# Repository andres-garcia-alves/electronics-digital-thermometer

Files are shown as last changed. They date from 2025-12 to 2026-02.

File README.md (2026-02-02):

# Digital Thermometer

Arduino code for a digital thermometer (temperature, humidity and heat index) with auto-OFF functionality.

&nbsp;

This project use the following electronic components:
- 1 x Arduino UNO / Nano v3
- 1 x DHT11 temperature/humidity sensor
- 1 x Display 5461AS, 7 segment, 4 digit, common anode
- 8 x 1k ohm resistors
- 1 x 10k ohm resistor
- 1 x Transistor BC547 NPN
- 1 x Electrolitic capacitor 470uF 10v
- 1 x Push-button
- 1 x Batery 9v

The circuit:
- Pressing the push-button charges the capacitor and puts the transistor in conducting state.
- After the button is released, the capacitor continues to power the base of the transistor for around 20 seconds.
- The current through the transistor powers the Arduino (and rest of the thermometer).
- Arduino constrols the temperature+humidity measurement and the multiplexing process for the 4 digit display.

Notes:
- This thermometer automatically turns off approximately 20 seconds after activation.
- To increase this time, change the capacitor to one of higher capacitance.
- Edit `Definitions.h` to adjust configured display pins to your own display model.

&nbsp;

### Screenshots

| Schematics Diagram | PCB Layout |
|---|---|
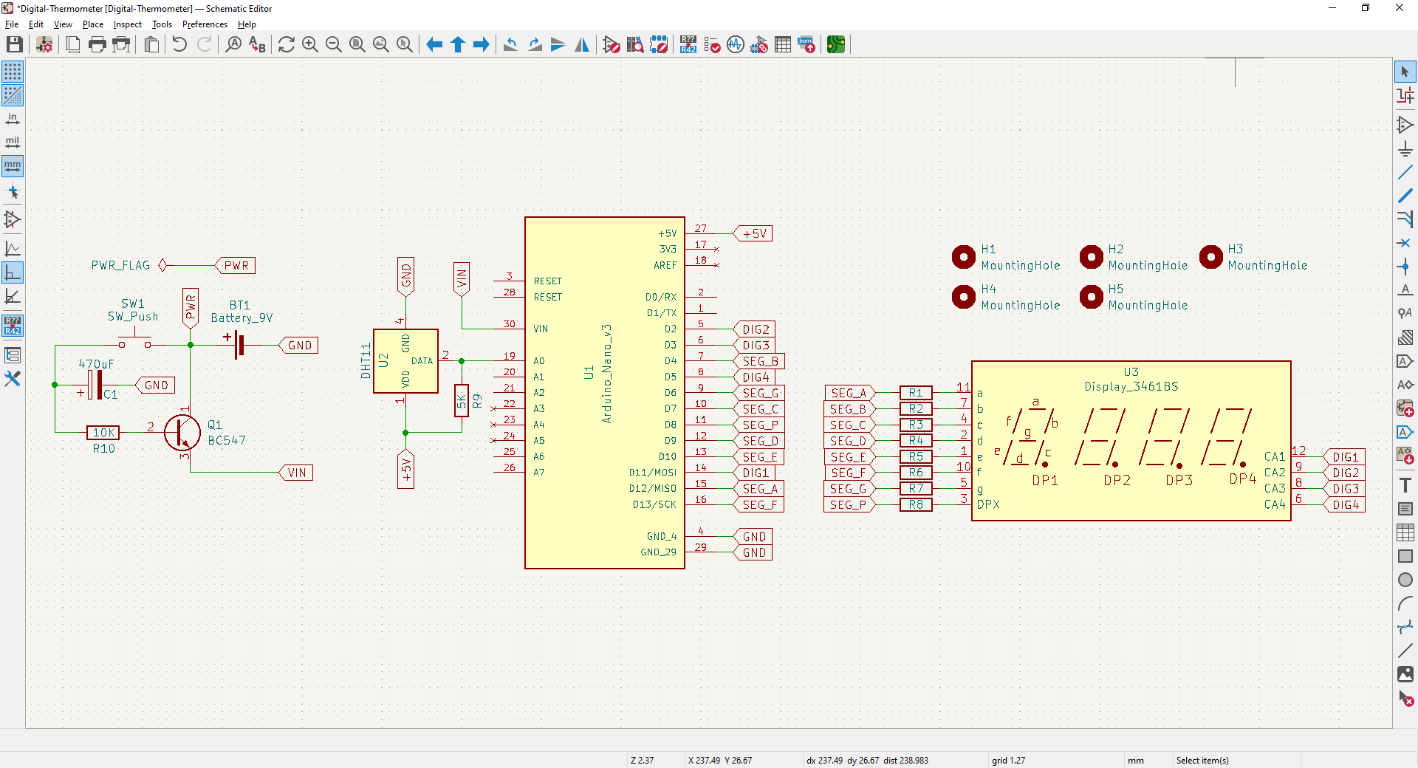
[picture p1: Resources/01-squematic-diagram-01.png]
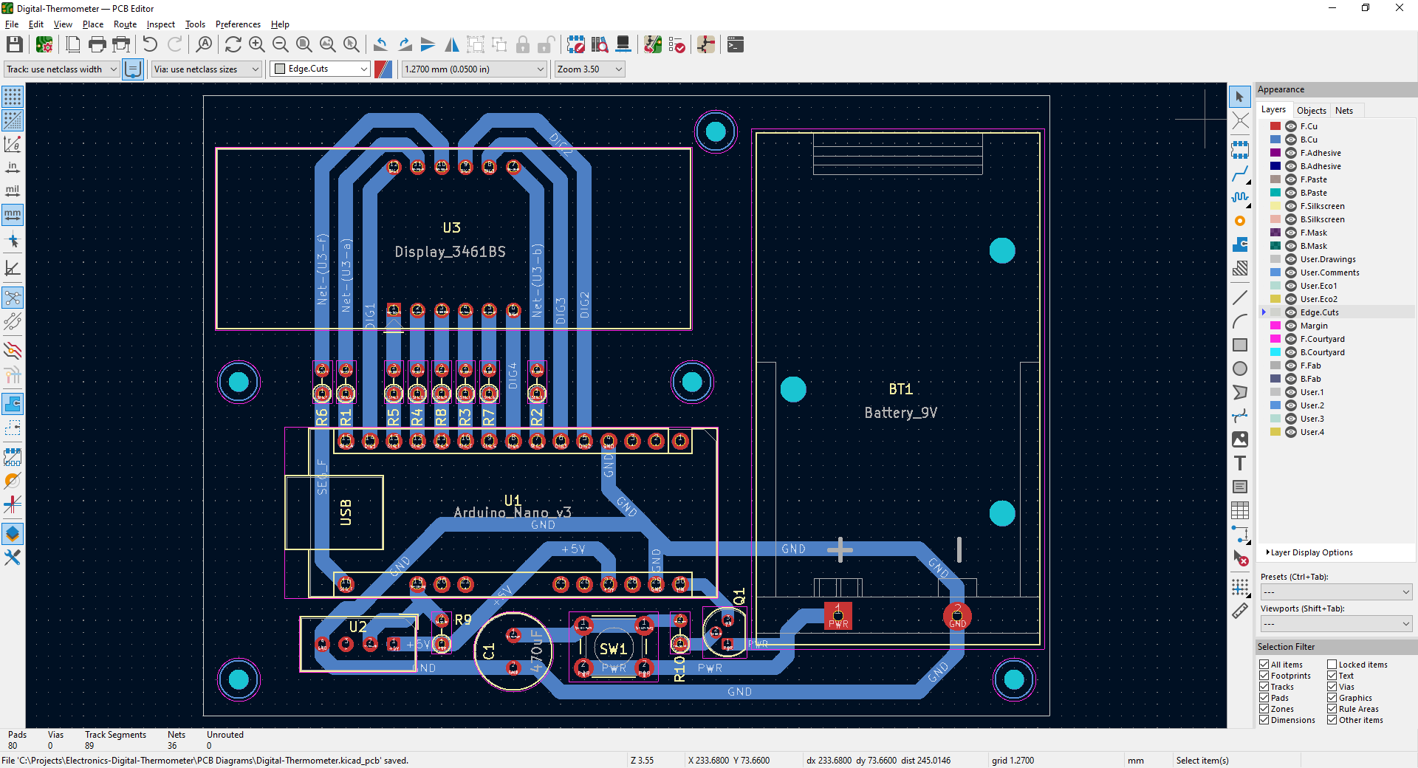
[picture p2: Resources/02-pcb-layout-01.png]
|  |  |

| PCB 3D Render | PCB 3D Render |
|---|---|
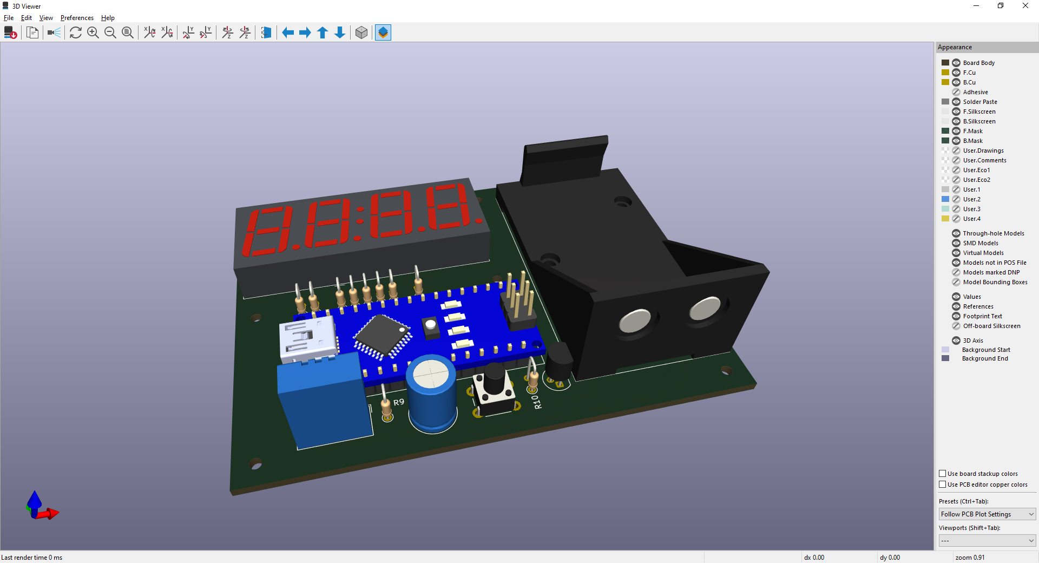
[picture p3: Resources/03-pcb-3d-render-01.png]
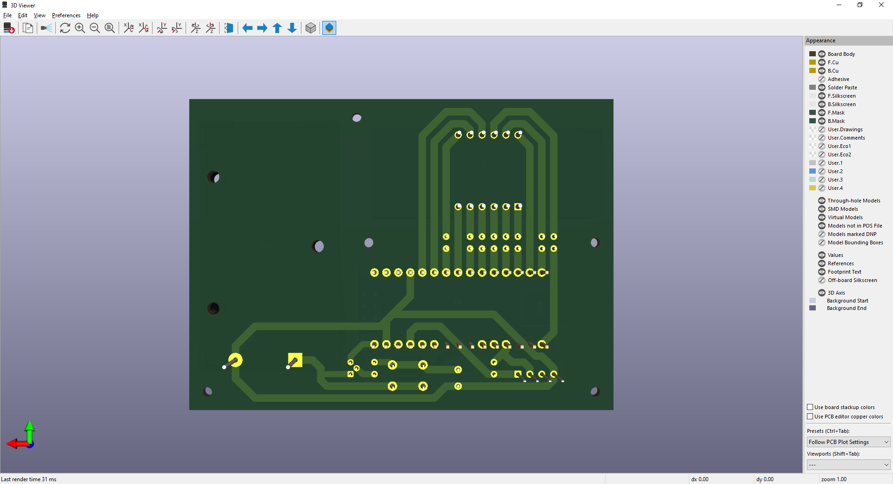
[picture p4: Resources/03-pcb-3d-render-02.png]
|  |  |

| Prototype | Building |
|---|---|
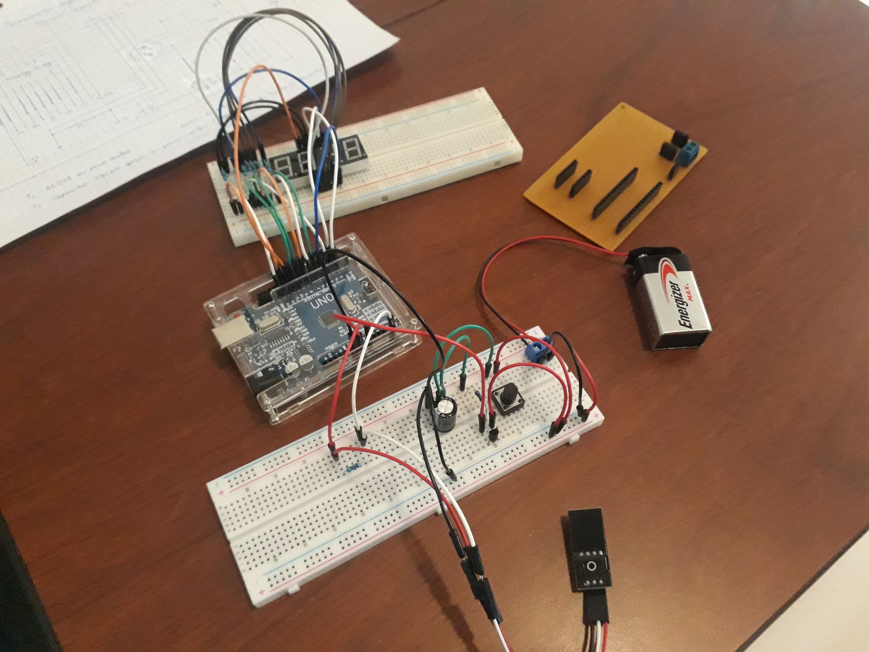
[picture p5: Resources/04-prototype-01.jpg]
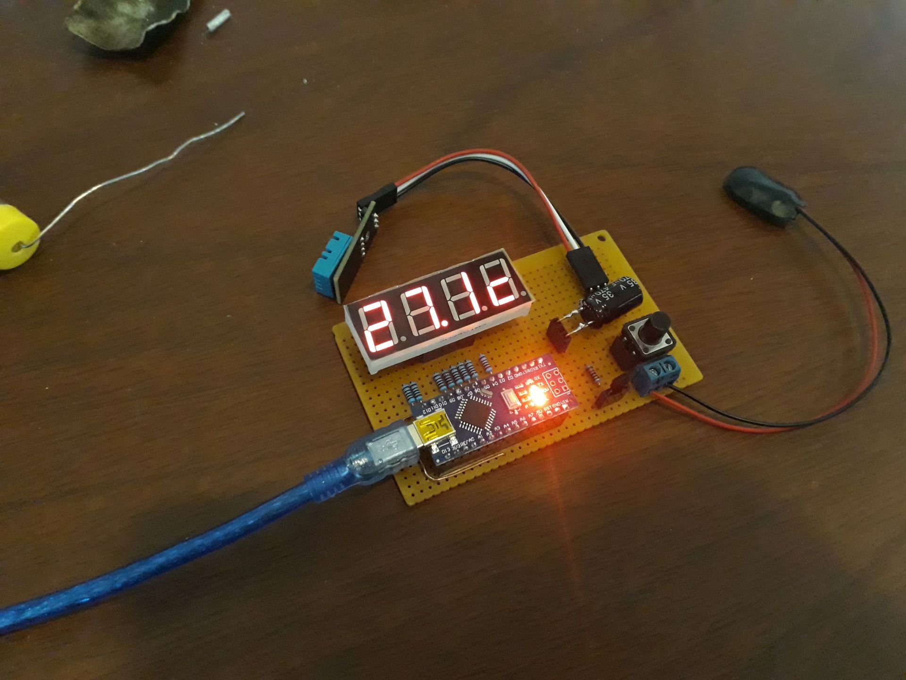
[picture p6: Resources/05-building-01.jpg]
|  |  |

| Building | Building |
|---|---|
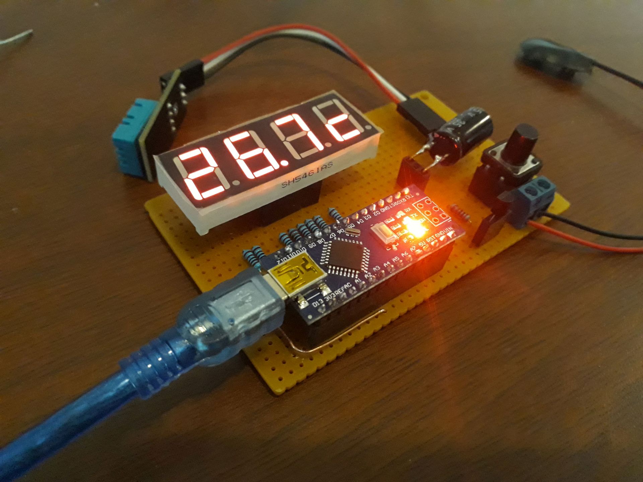
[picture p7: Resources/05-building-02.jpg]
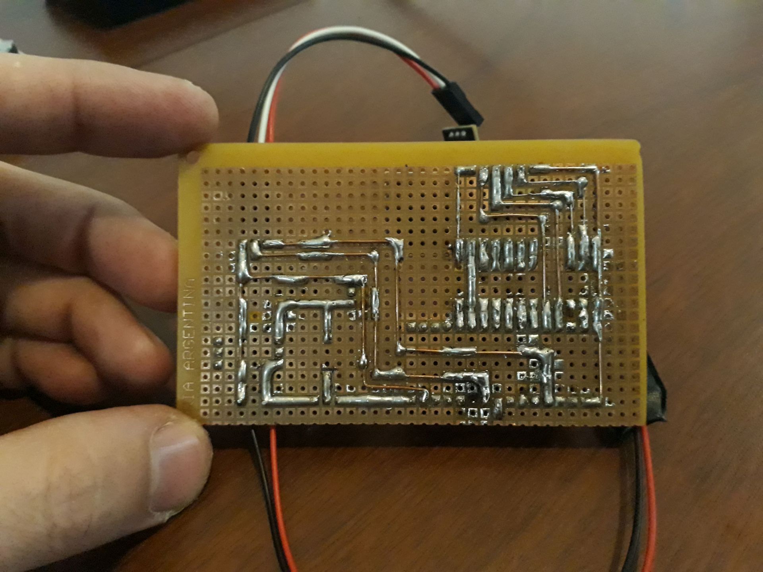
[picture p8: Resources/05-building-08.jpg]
|  |  |

| Box Shaping | Box Shaping |
|---|---|
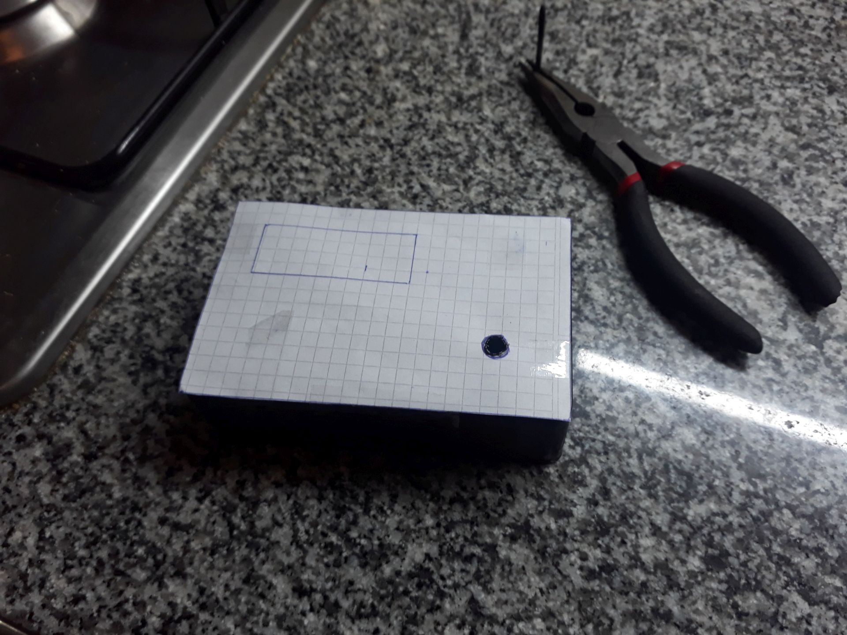
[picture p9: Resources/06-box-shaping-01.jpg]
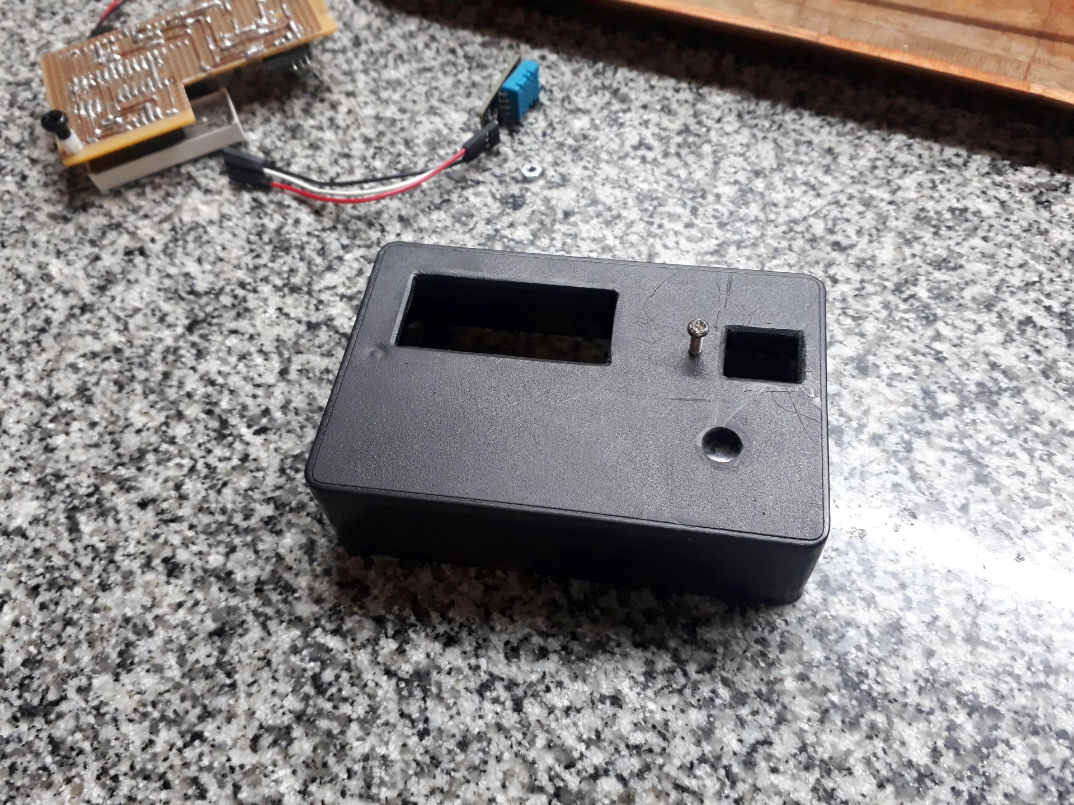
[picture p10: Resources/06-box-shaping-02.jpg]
|  |  |

| Project Final | Project Final (YouTube video) |
|---|---|
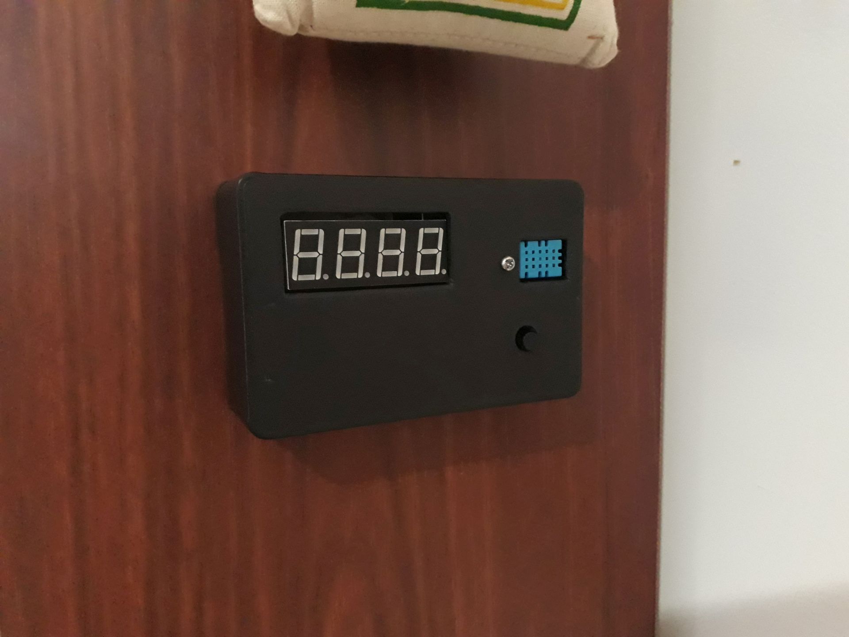
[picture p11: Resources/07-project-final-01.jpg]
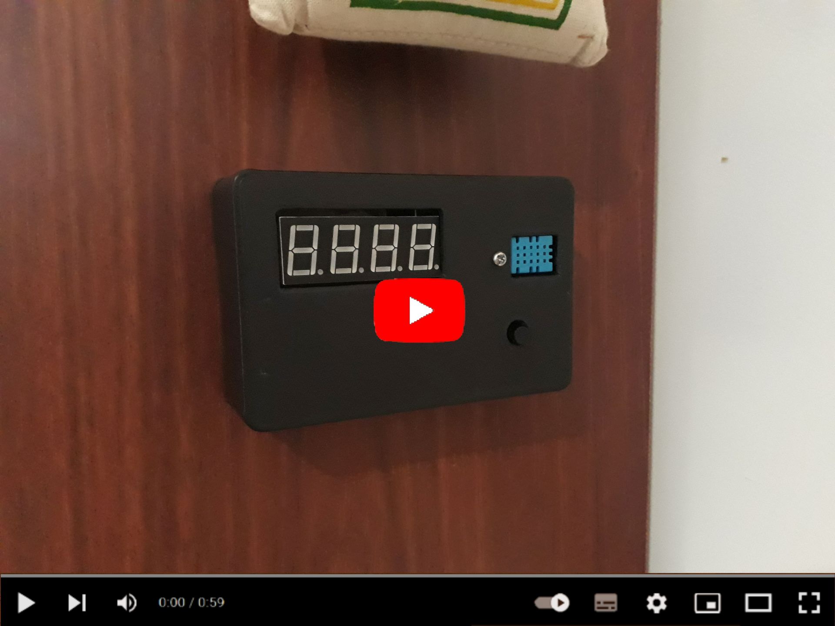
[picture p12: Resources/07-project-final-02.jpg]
(https://youtu.be/rd8s7MKu5Gk)
|  |  |

See 'Rescources' sub-folder for more pictures & videos of the project.

&nbsp;

### Version History

v1.0 (2022.12.08) - Initial release.  
v1.1 (2022.12.10) - Re-arrange LEDs pin-out to simplefy PCB.  
v1.2 (2022.12.11) - Using masked bits to improve character display.  
v1.3 (2023.03.28) - Use of headers for better readability.  
v1.4 (2023.04.08) - Hardware re-desing.  
v1.5 (2025.12.20) - Update project structure.  
v1.6 (2025.12.26) - Adding KiCAD 9 schematics and PCB diagrams.  
v1.7 (2026.02.01) - Minor PCB improvements.  

&nbsp;

This source code is licensed under GPL v3.0  
Please send me your feedback about this project: andres.garcia.alves@gmail.com

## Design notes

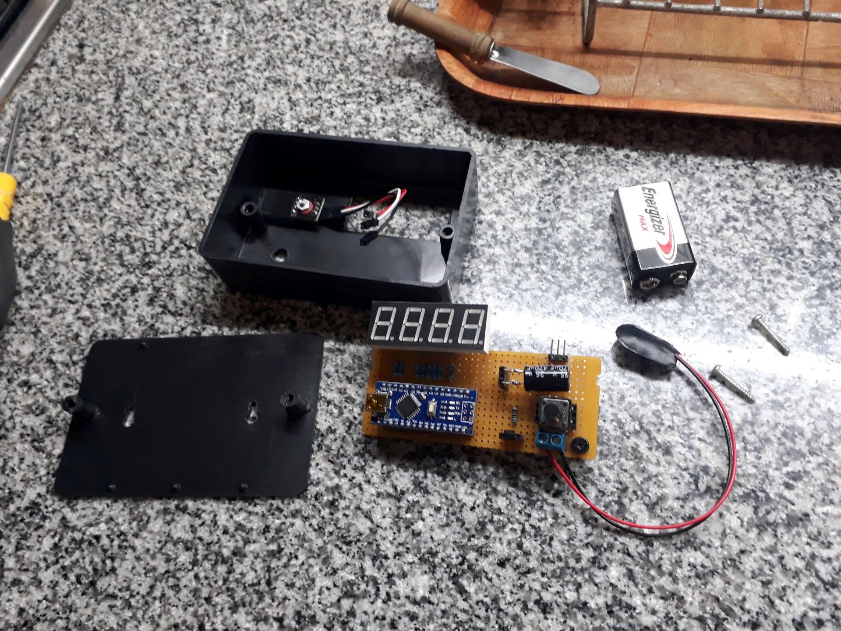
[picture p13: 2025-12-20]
Resources/06-box-shaping-03.jpg

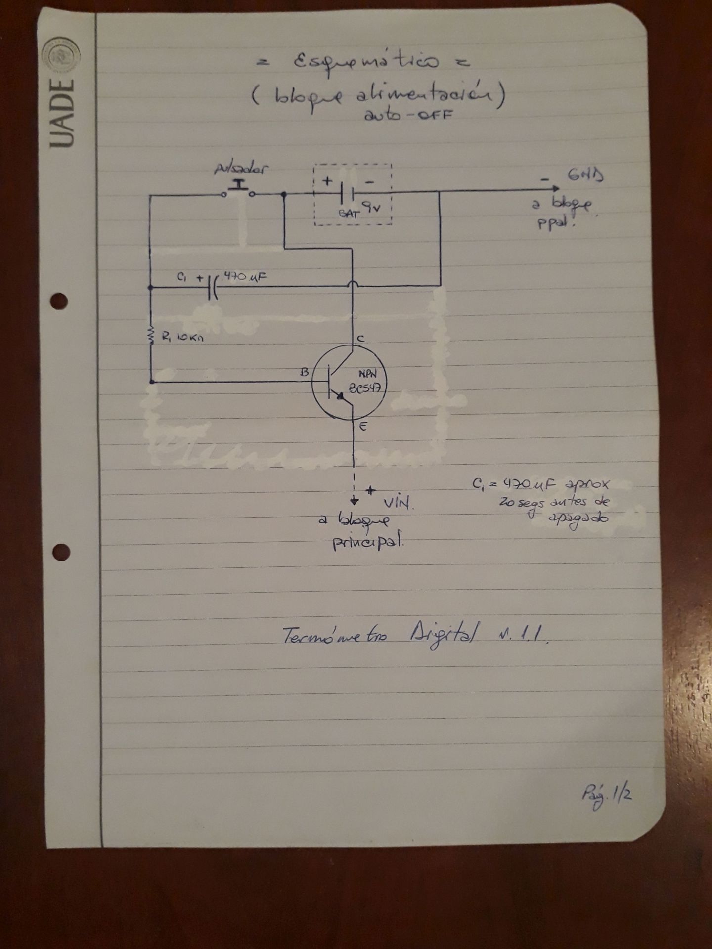
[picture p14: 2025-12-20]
Resources/01-squematic-diagram-02.jpg

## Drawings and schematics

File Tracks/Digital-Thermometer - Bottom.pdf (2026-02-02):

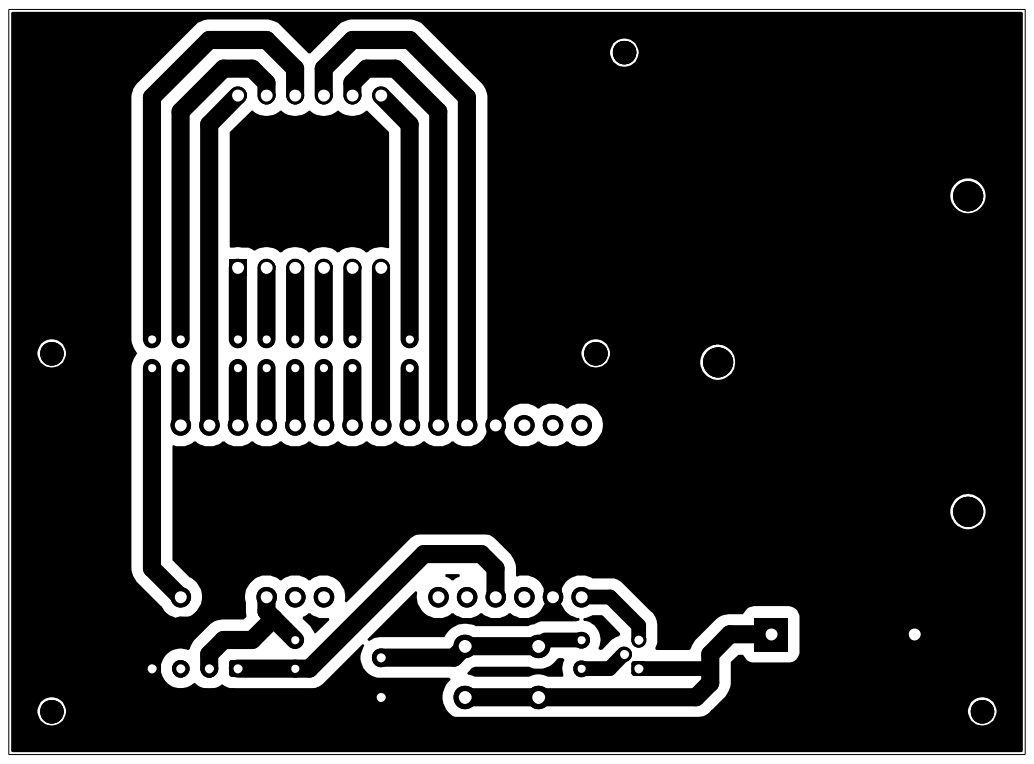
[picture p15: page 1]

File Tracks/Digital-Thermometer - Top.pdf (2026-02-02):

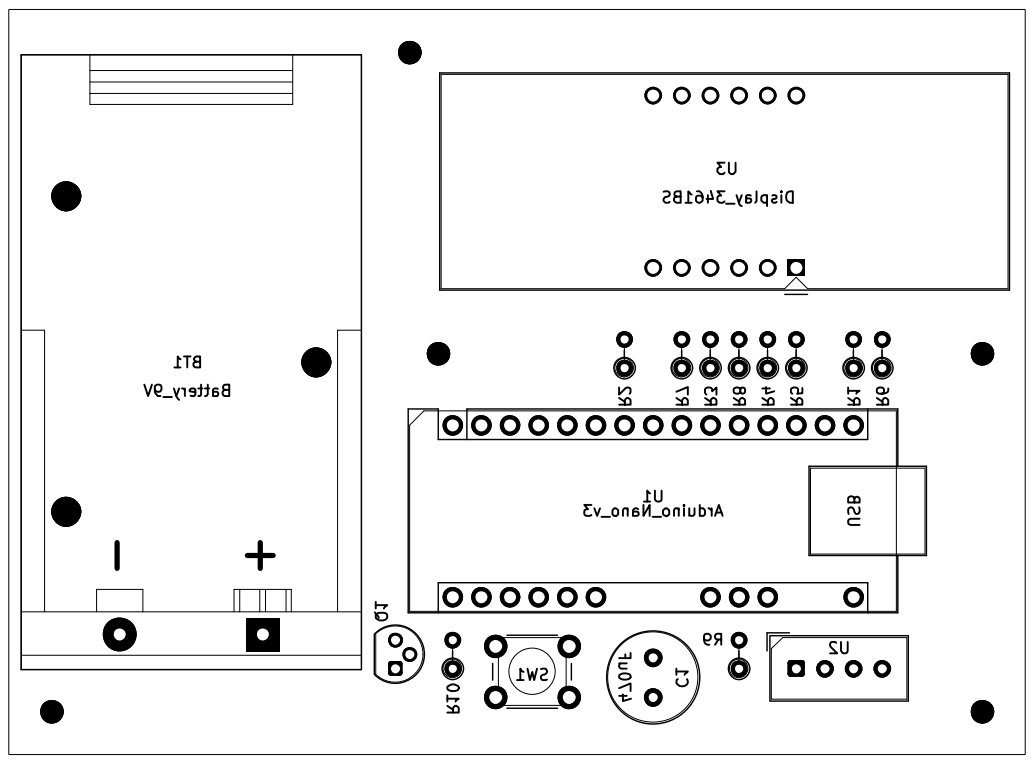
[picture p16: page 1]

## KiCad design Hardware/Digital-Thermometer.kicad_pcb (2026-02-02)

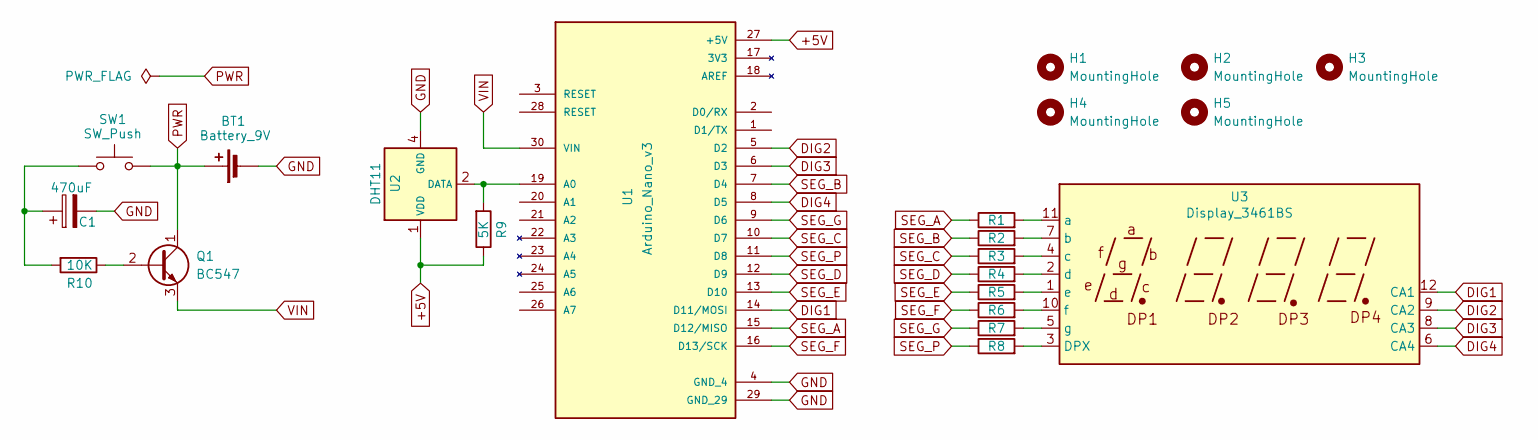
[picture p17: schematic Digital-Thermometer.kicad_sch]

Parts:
BT1: Battery_9V; BatteryHolder_Eagle_12BH611-GR
C1: 470uF; C_Radial_D8.0mm_H11.5mm_P3.50mm
H1, H2, H3, H4, H5: MountingHole; MountingHole_2mm
Q1: BC547; TO-92
R1, R2, R3, R4, R5, R6, R7, R8: 1K; R_Axial_DIN0204_L3.6mm_D1.6mm_P2.54mm_Vertical
R9: 5K; R_Axial_DIN0204_L3.6mm_D1.6mm_P2.54mm_Vertical
R10: 10K; R_Axial_DIN0204_L3.6mm_D1.6mm_P2.54mm_Vertical
SW1: SW_Push; SW_PUSH_6mm_H8mm
U1: Arduino_Nano_v3
U2: DHT11; Aosong_DHT11_5.5x12.0_P2.54mm
U3: Display_3461BS; CA56-12EWA

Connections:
+5V: R9.1, U1.27 (+5V), U2.1 (VDD)
DIG1: U1.14 (D11/MOSI), U3.12 (CA1)
DIG2: U1.5 (D2), U3.9 (CA2)
DIG3: U1.6 (D3), U3.8 (CA3)
DIG4: U1.8 (D5), U3.6 (CA4)
GND: BT1.2 (-), C1.2, U1.4 (GND_4), U1.29 (GND_29), U2.4 (GND)
unnamed: C1.1, R10.2, SW1.1
unnamed: Q1.2 (B), R10.1
unnamed: R9.2, U1.19 (A0), U2.2 (DATA)
unnamed: R8.2, U3.3 (DPX)
unnamed: R1.2, U3.11 (a)
unnamed: R2.2, U3.7 (b)
unnamed: R3.2, U3.4 (c)
unnamed: R4.2, U3.2 (d)
unnamed: R5.2, U3.1 (e)
unnamed: R6.2, U3.10 (f)
unnamed: R7.2, U3.5 (g)
PWR: BT1.1 (+), Q1.1 (C), SW1.2
SEG_A: R1.1, U1.15 (D12/MISO)
SEG_B: R2.1, U1.7 (D4)
SEG_C: R3.1, U1.10 (D7)
SEG_D: R4.1, U1.12 (D9)
SEG_E: R5.1, U1.13 (D10)
SEG_F: R6.1, U1.16 (D13/SCK)
SEG_G: R7.1, U1.9 (D6)
SEG_P: R8.1, U1.11 (D8)
VIN: Q1.3 (E), U1.30 (VIN)

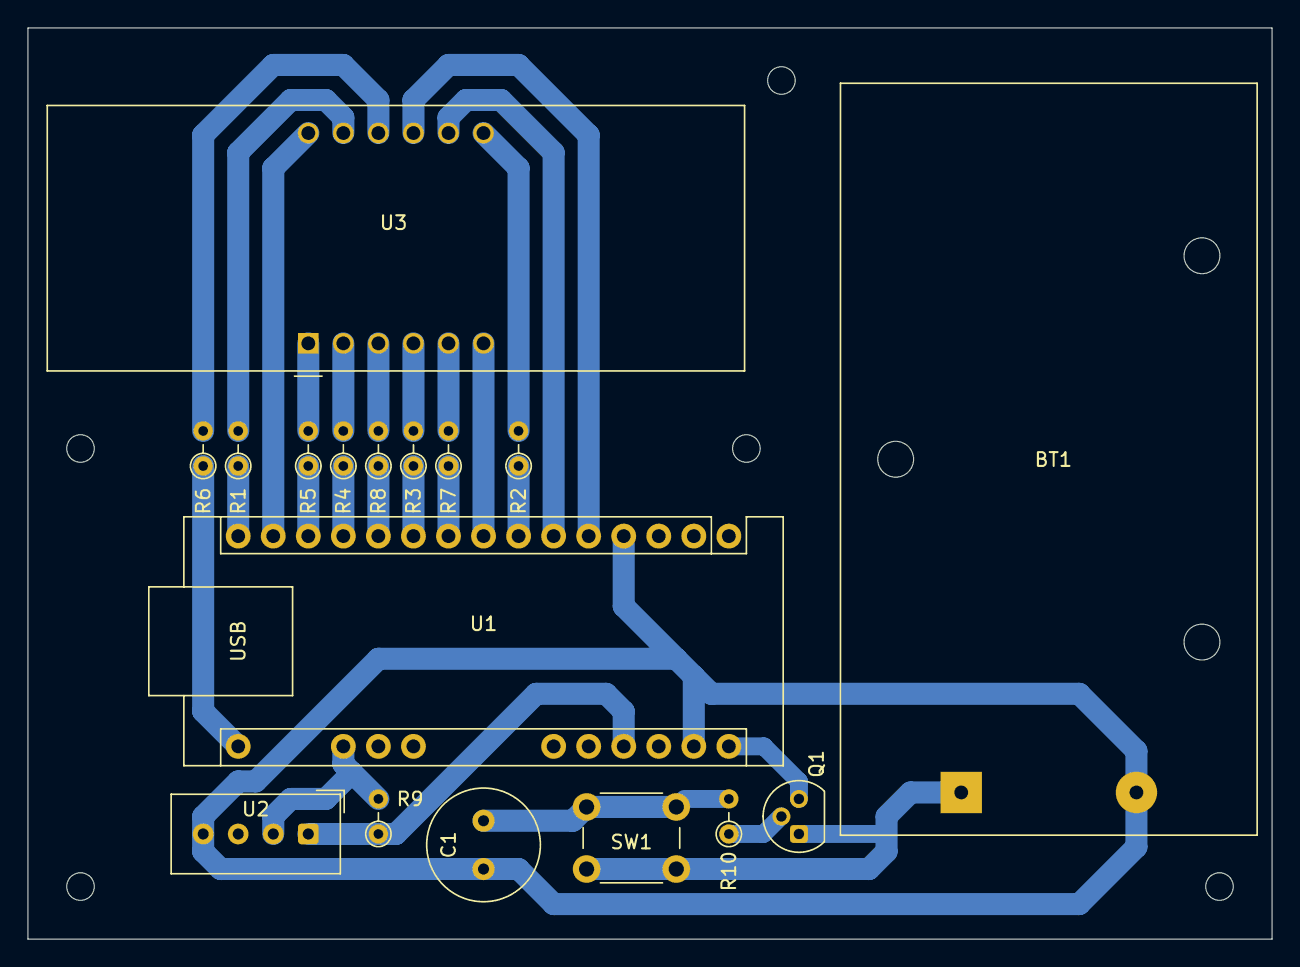
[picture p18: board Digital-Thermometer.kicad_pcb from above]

Board: 2 copper layers, 90.2 x 66.0 mm, 22 parts (0 on the bottom side), 27 nets.

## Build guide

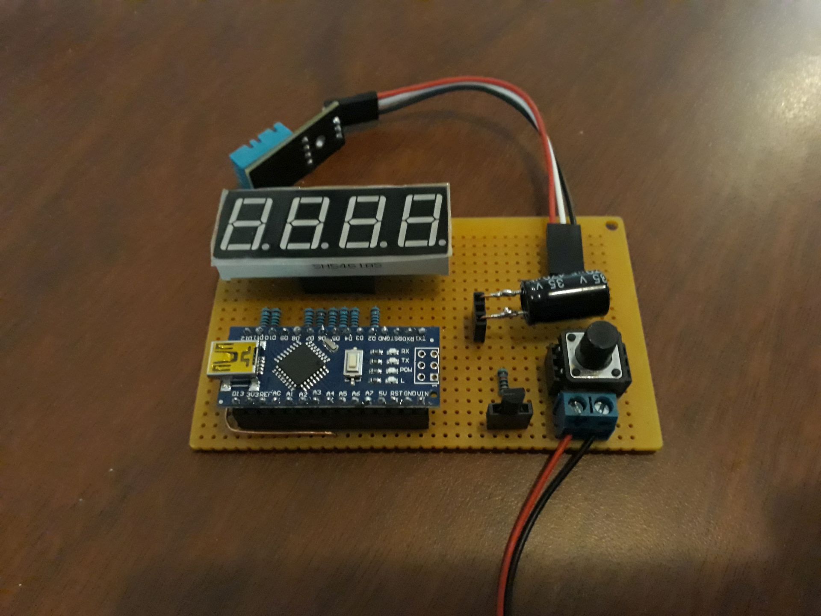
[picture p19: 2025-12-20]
Resources/05-building-05.jpg

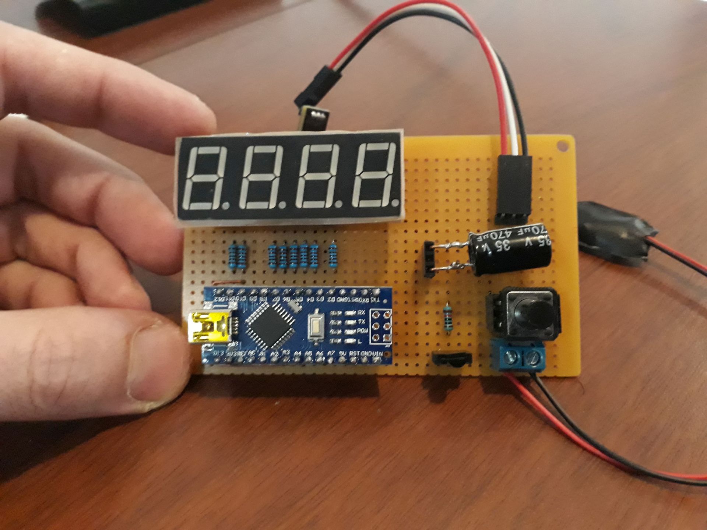
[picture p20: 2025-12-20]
Resources/05-building-07.jpg

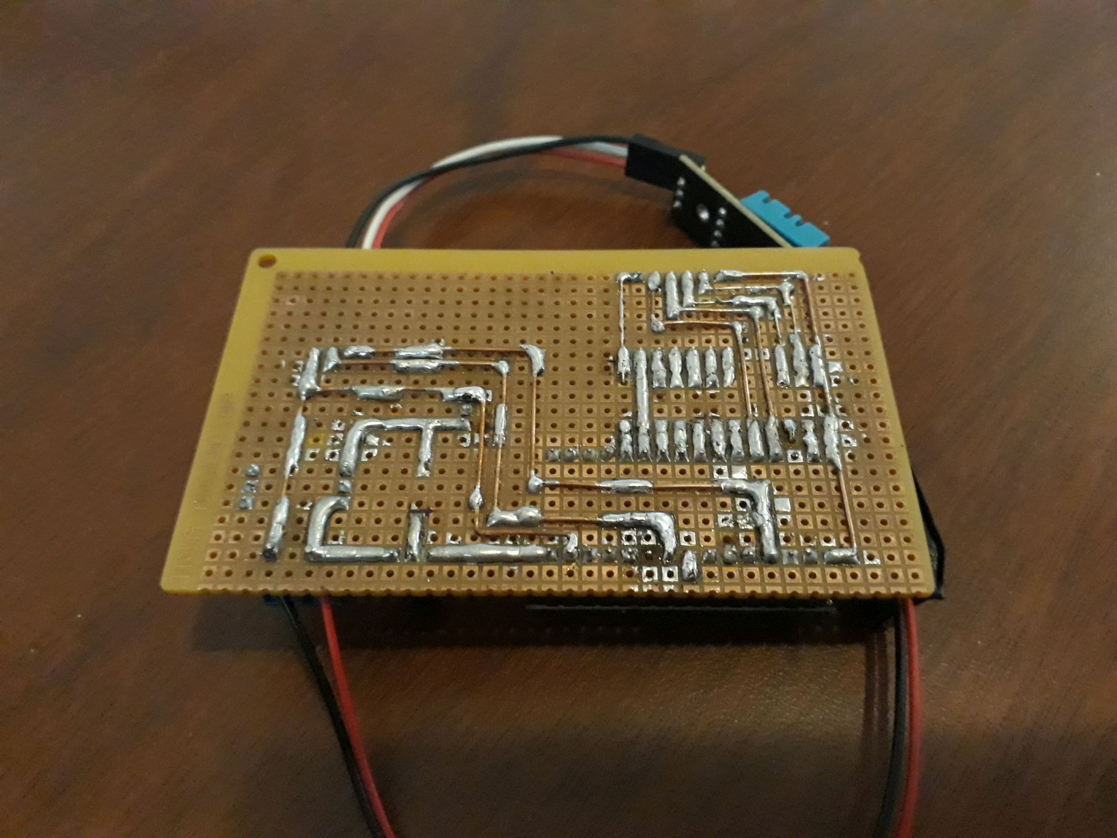
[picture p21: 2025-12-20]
Resources/05-building-06.jpg

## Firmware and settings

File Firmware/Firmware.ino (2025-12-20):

/*
Digital Thermometer v1.4

Created by: Andres Garcia Alves <andres.garcia.alves@gmail.com>
Microcontroller: Arduino Nano (ATMega328 @16Mhz)

Version 1.0, 2022.12.08 - Initial release.
Version 1.1, 2022.12.10 - Re-arrange LEDs pin-out to simplefy PCB.
Version 1.2, 2022.12.11 - Using masked bits to improve character display.
Version 1.3, 2023.03.28 - Use of headers for better readability.
Version 1.4, 2023.04.08 - Hardware re-desing.

This source code is licensed under GPL v3.0

Pinout (4 digit multiplexed 7-segment display):

      ***(A)***
  (F) *       * (B)
      ***(G)***
  (E) *       * (C)
      ***(D)***

D00 -> debug (serial port)
D01 -> debug (serial port)
D02 -> output to F segment of selected digit
D03 -> output to A segment of selected digit
D04 -> output to selector pin for digit 0
D05 -> output to E segment of selected digit
D06 -> output to D segment of selected digit
D07 -> output to dot point of selected digit
D08 -> output to C segment of selected digit
D09 -> output to G segment of selected digit
D10 -> output to selector pin for digit 1
D11 -> output to B segment of selected digit
D12 -> output to selector pin for digit 2
D13 -> output to selector pin for digit 3

*/

#include <DHT.h>
#include "Definitions.h"
#include "Debug.h"
#include "Display_4d.h"


// variables
DHT dht(SENSOR_DHT_DATA, SENSOR_TYPE);

eDataMode dataMode = NONE;
byte currentDigit = 0;

unsigned long int currentMillis = 0;
unsigned long int nextSensorTick = 0;
unsigned long int nextDataModeTick = 0;
byte seansorFailures = 0;


void setup() {

  #if DEBUG
  Serial.begin(9600);
  #endif

  // pins mode
  pinMode(DISPLAY_DIGIT_0, OUTPUT);
  pinMode(DISPLAY_DIGIT_1, OUTPUT);
  pinMode(DISPLAY_DIGIT_2, OUTPUT);
  pinMode(DISPLAY_DIGIT_3, OUTPUT);
  
  pinMode(DISPLAY_LED_A, OUTPUT);
  pinMode(DISPLAY_LED_B, OUTPUT);
  pinMode(DISPLAY_LED_C, OUTPUT);
  pinMode(DISPLAY_LED_D, OUTPUT);
  pinMode(DISPLAY_LED_E, OUTPUT);
  pinMode(DISPLAY_LED_F, OUTPUT);
  pinMode(DISPLAY_LED_G, OUTPUT);
  pinMode(DISPLAY_LED_DOT, OUTPUT);

  // initialize DHT sensor
  pinMode(SENSOR_DHT_VCC, OUTPUT);
  digitalWrite(SENSOR_DHT_VCC, HIGH);
  dht.begin();

  // initial text
  delay(1200);
}


void loop() {

  currentMillis = millis();

  // sensor reading
  if (currentMillis > nextSensorTick) {

    // next sensor reading
    nextSensorTick = currentMillis + SENSOR_INTERVAL;

    // sensor reading
    sensorMeasure = readSensor();
    displayText = buildDisplayText(sensorMeasure);

    #if DEBUG
    updateSerialPort(sensorMeasure);
    #endif
  }

  // data mode
  if (currentMillis > nextDataModeTick) {
    nextDataModeTick = currentMillis + MODE_INTERVAL; // next mode change

    switch (dataMode) {
      case NONE:        dataMode = TEMPERATURE; break;
      case TEMPERATURE: dataMode = HEAT_INDEX;  break;
      case HEAT_INDEX:  dataMode = HUMIDITY;    break;
      case HUMIDITY:    dataMode = TEMPERATURE; break;
    }
  }

  // update display & move to next digit
  updateDisplay(displayText, dataMode, currentDigit);
  currentDigit = (++currentDigit) % 4; // valid range 0-3

  delay(5);
}


SensorMeasure readSensor() {
  SensorMeasure aux;

  aux.temperature = dht.readTemperature();  // temperature (celsius degrees)
  aux.humidity = dht.readHumidity();        // humidity

  // check for sensor-reading errors
  if (isnan(aux.temperature) || isnan(aux.humidity)) {
    aux.valid = false;
    seansorFailures++;
    
    #if DEBUG
    Serial.println("Error obteniendo los datos del sensor DHT11");
    /*aux.valid = true;
    aux.temperature = 88.8;
    aux.heatIndex = 88.8;
    aux.humidity = 0;*/
    #endif

  } else { // calculte heat-index (celsius degrees)
    aux.valid = true;
    seansorFailures = 0;
    aux.heatIndex = dht.computeHeatIndex(aux.temperature, aux.humidity, false);
  }

  return aux;
}


DisplayText buildDisplayText(SensorMeasure sensorMeasure) {
  DisplayText aux;

  if (sensorMeasure.valid) {
    aux.temperature = String(sensorMeasure.temperature, 1);
    aux.temperature.replace(".", "");
    aux.temperature += "c";
    aux.temperatureDotPos = 1;
  
    aux.heatIndex = String(sensorMeasure.heatIndex, 1);
    aux.heatIndex.replace(".", "");
    aux.heatIndex += "C";  
    aux.heatIndexDotPos = 1;
  
    aux.humidity = String(sensorMeasure.humidity, 1);
    aux.humidity.replace(".", "");
    aux.humidity.setCharAt(2, " ");
    aux.humidity += "h";
    aux.humidityDotPos = -1;

  } else {
    String failureText = "----" + String(seansorFailures);
    failureText = failureText.substring(failureText.length() - 4);

    aux.temperature = failureText;
    aux.temperatureDotPos = -1;
    aux.heatIndex = failureText;
    aux.heatIndexDotPos = -1;
    aux.humidity = failureText;
    aux.humidityDotPos = -1;
  }

  return aux;
}

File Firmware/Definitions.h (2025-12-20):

#ifndef DEFINITIONS_H
#define DEFINITIONS_H

// digit selector pins
#define DISPLAY_DIGIT_0   13
#define DISPLAY_DIGIT_1   10
#define DISPLAY_DIGIT_2   9
#define DISPLAY_DIGIT_3   3

// display segment pins
#define DISPLAY_LED_A     12
#define DISPLAY_LED_B     2
#define DISPLAY_LED_C     5
#define DISPLAY_LED_D     7
#define DISPLAY_LED_E     8
#define DISPLAY_LED_F     A4
#define DISPLAY_LED_G     4
#define DISPLAY_LED_DOT   6

// DHT sensor type & pins
#define SENSOR_TYPE       DHT11
#define SENSOR_DHT_VCC    A0
#define SENSOR_DHT_DATA   A5

#define MODE_INTERVAL     6000
#define SENSOR_INTERVAL   MODE_INTERVAL * 3

// data structures
struct SensorMeasure {
  bool valid = true;
  float temperature = 0;
  float heatIndex = 0;
  float humidity = 0;
} sensorMeasure;

struct DisplayText {
  String temperature = " 00c";
  String heatIndex = " 00C";
  String humidity = " 0 h";
  byte temperatureDotPos = 1;
  byte heatIndexDotPos = 1;
  byte humidityDotPos = -1;
} displayText;

enum eDataMode { NONE, TEMPERATURE, HEAT_INDEX, HUMIDITY };

#endif

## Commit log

2025-12-27 Adding KiCAD 9 schematics and PCB diagrams.
    [Digital-Thermometer.kicad_pcb, Digital-Thermometer.kicad_sch]
2025-12-27 Adding KiCAD 9 schematics and PCB diagrams
2026-02-02 Minor PCB improvements
    [Digital-Thermometer.kicad_pcb, Digital-Thermometer.kicad_sch]
